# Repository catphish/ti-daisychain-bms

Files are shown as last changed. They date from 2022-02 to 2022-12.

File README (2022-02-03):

TI Daisychain BMS Master
========================

BMS master for daisychained bq76PL455A slave modules.

This board will communicate with up to 3 strings of bq76PL455A battery
modules. Each string supports up to 16 modules, and each module supports
up to 16 cells. A common configuration is 3 strings of 6 modules but any
combination is supported.

The board will read the voltages of all detected cells and will perform
balancing as well as reporting data over CAN.

Connector J1
=============

------------------------
| CANH | WAKE1 | WAKE2 |
| CANL |  GND  |  +12V |
------------------------

The low voltage connector J1 has 3 functions:

1) Connect +12v to a permanent positive suppy (5v - 14v)
2) Connect CANH and CANL to a CAN bus.
3) Connect WAKE1 and WAKE2 to switched voltage sources

If either WAKE1 OR WAKE2 is live (+5v to +14v) theh the board will wake
up and monitor the pack. If both are off (0v) then the board will finish
any in-progress balancing, then go into a low power sleep mode.

It is recommended to connect WAKE1 to ignition live, and WAKE2 to a 12V
output generated by a charger. This will ensure that the cells are monitored
during both charge and discharge.

Connector J2, J3, J4
====================

Each of the BATT1, BATT2 and BATT3 (J2,J3,J4) may be connected to the data
pins of a bq76PL455A battery module. All three are optional, and all three
support a full chain of up to 16 battery modules, or any partial chain.
Chain lengths do not have to be matched. The pinout of the battery module
is beyong the scope of this document.

Power Modes
===========

When either WAKE1 or WAKE2 are high, the module will enter active mode. In
this mode, it will continuously monitor the voltage of all attached cells.
Data including the pack voltage, high and low cell voltages, and temperatures
will be send to the CAN bus at 1 second intervals. Balancing will take place
if necessary. For further details of balancing see the next section.

When WAKE1 and WAKE2 are both low, and balancing is complete, the board will
enter a low power sleep mode. In this mode, the board consumes approximately
600uA (0.6mA) at 12V and will perform no actions until woken again. The
bq76PL455A modules will also anter a low power state, consuming close to zero
power from the high voltage pack.

Balancing
=========

If any cell voltage is detected as being higher than 4.0V and more than 10mV
higher than the lowest recorded cell voltage, it will be bled until one of
these ocnditions is no longer met. To prevent excessive heat, only one cell
in each battery (16 cell module) will be bled simultaneously. If multiple cells
meet the criteria, the cell with the highest voltage will be selected.
Balancing will be considered complete when no cells meet the criteria for
balancing.

CAN Messages Received
=====================

This modules does not receive CAN messages.

CAN Messages Sent
=================

--------------------------------------------------------------------------------
| CAN ID | Byte 0-3           | Byte 4-5          | Byte 6      | Byte 7       |
| 0x4f0  | Total Pack Voltage | Balance Threshold | Error count | Module count |
--------------------------------------------------------------------------------

Total pack voltage it the sum of all modules. For parallel packs this value
will be a multiple of the real pack voltage.

Balance threshold will be a non-zero value when balancing is active and
indicates the target voltage, generally this will be 10mV higher than the
minimum cell voltage.

--------------------------------------------------------------------
| CAN ID | Byte 0-1   | Byte 2-3   | Byte 4-5      | Byte 6-7      |
| 0x4f1  | Max Cell V | Min Cell V | Max Cell Temp | Min Cell Temp |
--------------------------------------------------------------------

All values are big endian. Voltage values should be interpreted by dividing
the value by 13107. Temperature values are 

The following calculation can be used to convert the readong for an External NTC to a temperature:

float temperature(uint16_t adc) {
  float r = 0.0000000347363427499292f * adc * adc - 0.001025770762903f * adc + 2.68235340614337f;
  float t = log(r) * -30.5280964239816f + 95.6841501312447f;
  return t;
}

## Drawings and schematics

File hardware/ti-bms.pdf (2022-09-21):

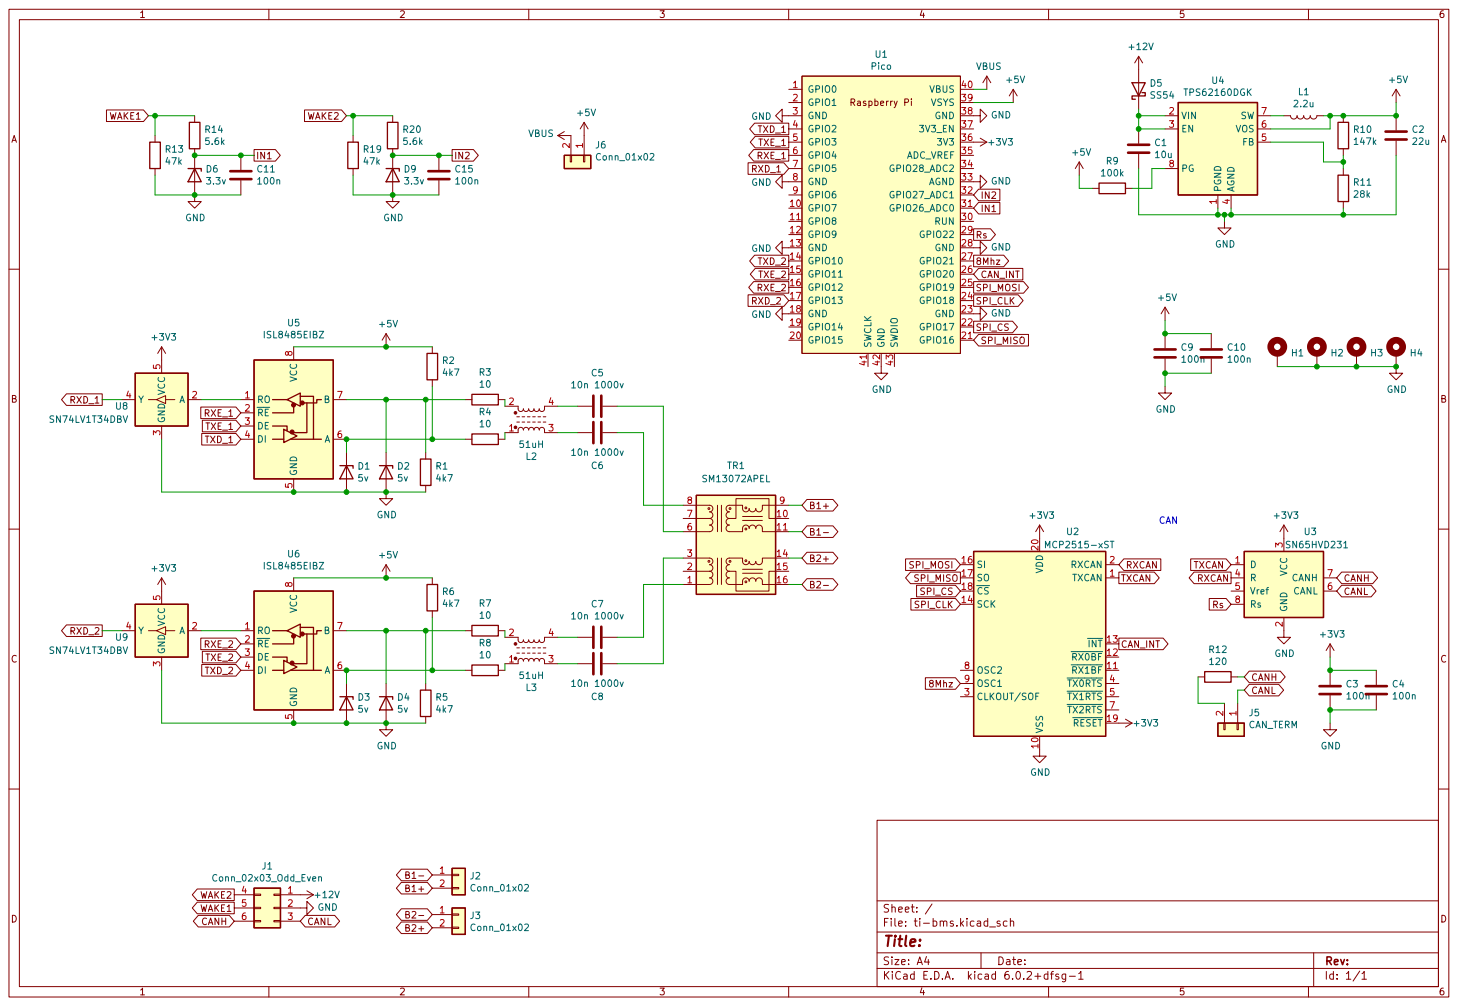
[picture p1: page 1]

4 FB 5 VOS 6 SW 7 PG 8 U4 TPS62160DGK GND
IN2 SPI_CS

File: ti-bms.kicad_sch Sheet: /
Id: 1/1 Title:

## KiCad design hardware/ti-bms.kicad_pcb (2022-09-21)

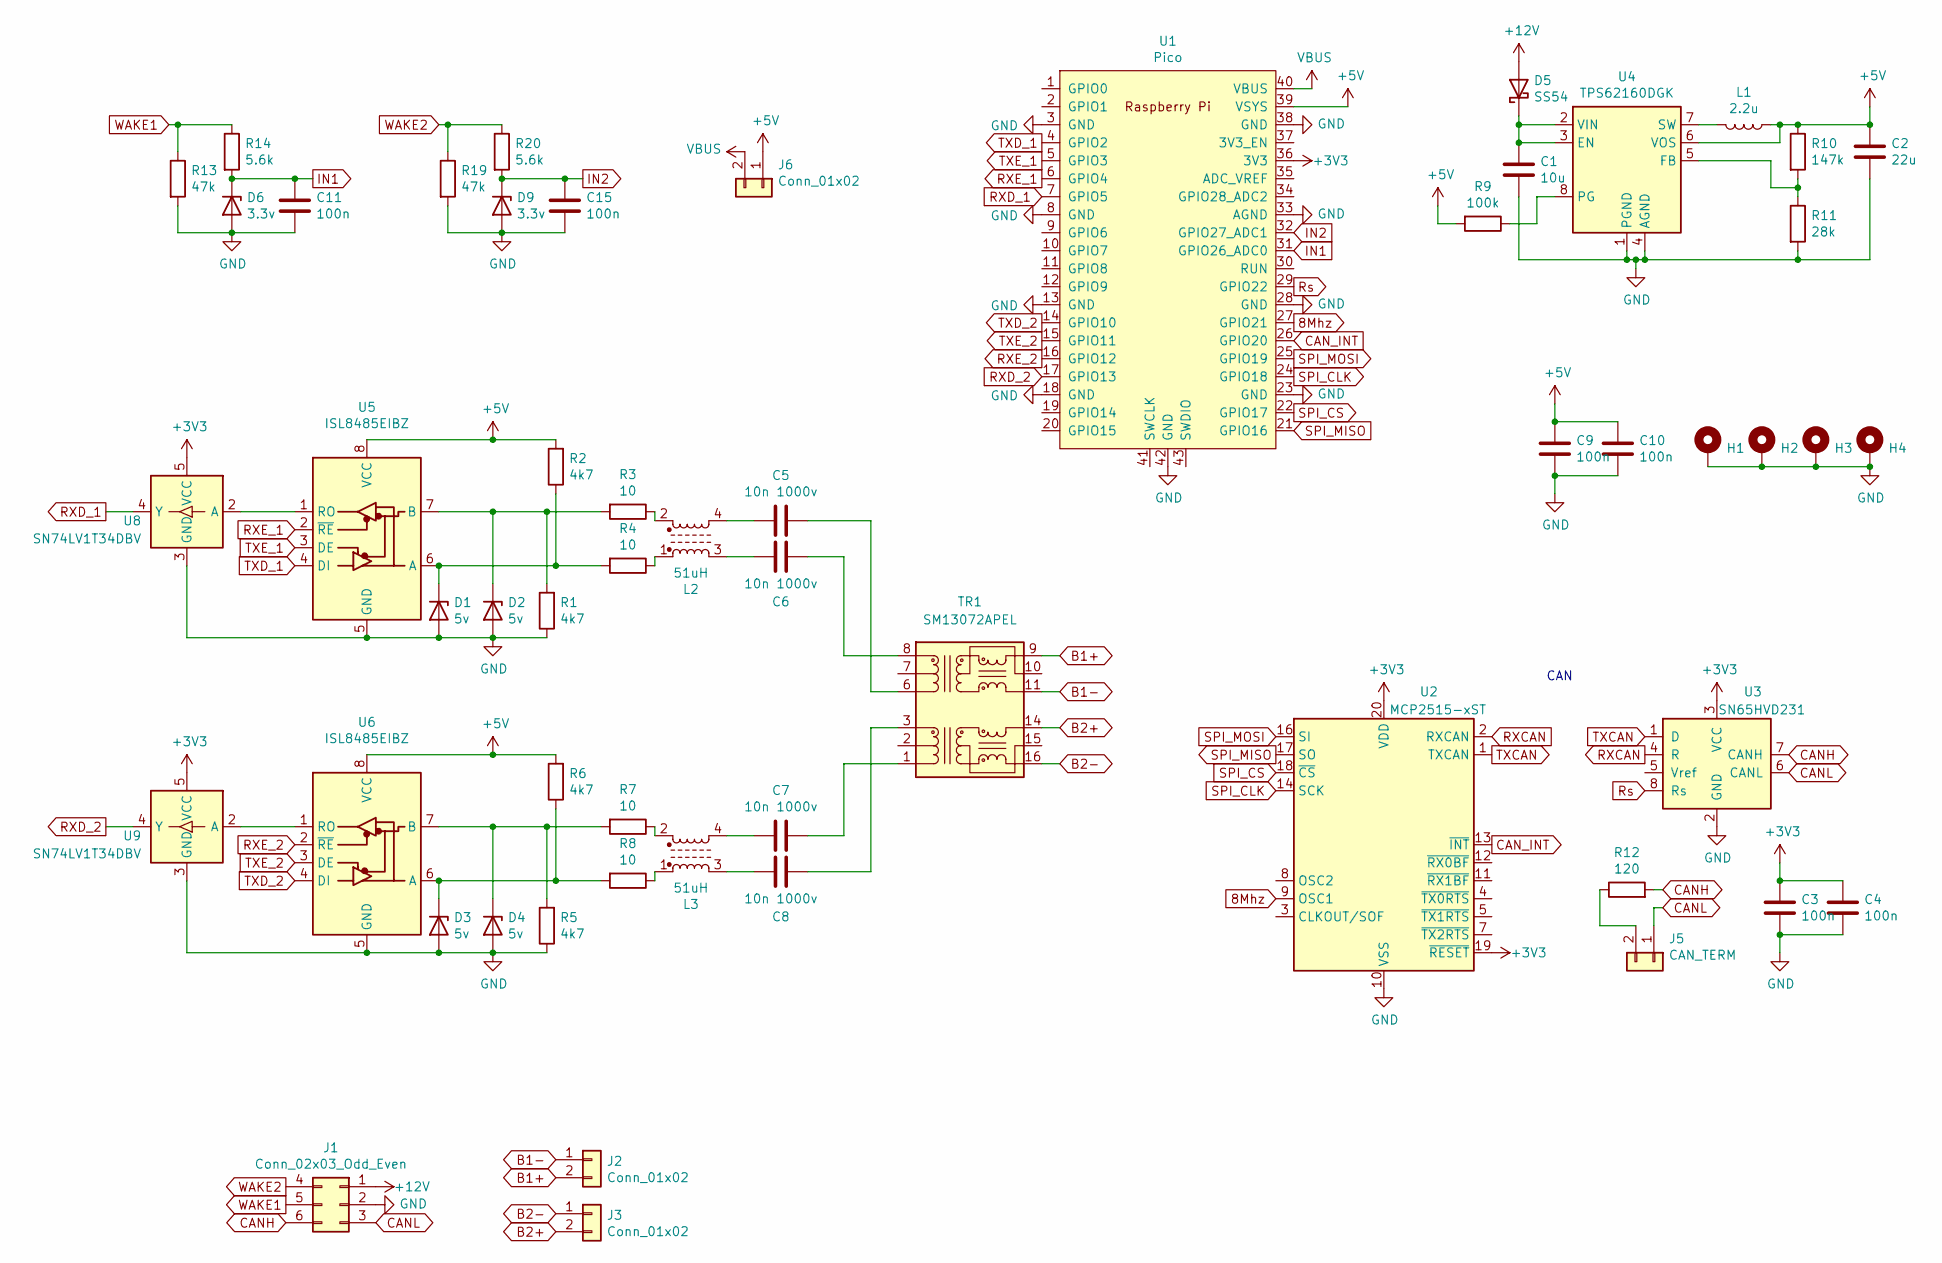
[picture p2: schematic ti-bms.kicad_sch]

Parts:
C1: 10u; C_1210_3225Metric; LCSC C77102
C2: 22u; C_1206_3216Metric; LCSC C5672
C3, C4, C9, C10, C11, C15: 100n; C_0603_1608Metric; LCSC C14663
C5, C6, C7, C8: 10n 1000v; C_1206_3216Metric; LCSC C9194
D1, D2, D3, D4: 5v; SOD882; LCSC C85401
D5: SS54; D_SMA; LCSC C22452
D6, D9: 3.3v; D_MiniMELF; LCSC C8056
H1, H2, H3, H4: MountingHole; MountingHole_3.2mm_M3_Pad
J1: Conn_02x03_Odd_Even; Molex_Micro-Fit_3.0_43045-0600_2x03_P3.00mm_Horizontal
J2, J3: Conn_01x02; Molex_Micro-Fit_3.0_43650-0200_1x02_P3.00mm_Horizontal
J5: CAN_TERM; PinHeader_1x02_P2.54mm_Vertical
J6: Conn_01x02; PinHeader_1x02_P2.54mm_Vertical
L1: 2.2u; L_Neosid_SMS-ME3015; LCSC C43389
L2, L3: 51uH; ACT45B-101-2P-TL003; LCSC C76584
R1, R2, R5, R6: 4k7; R_0603_1608Metric; LCSC C23162
R3, R4, R7, R8: 10; R_0603_1608Metric; LCSC C22859
R9: 100k; R_0603_1608Metric; LCSC C25803
R10: 147k; R_0603_1608Metric; LCSC C22878
R11: 28k; R_0603_1608Metric; LCSC C22989
R12: 120; R_1206_3216Metric; LCSC C17909
R13, R19: 47k; R_0603_1608Metric; LCSC C25819
R14, R20: 5.6k; R_0603_1608Metric; LCSC C23189
TR1: SM13072APEL; Transformer_Ethernet_Wuerth_749013011A; LCSC C129155
U1: Pico; RPi_Pico_SMD_TH
U2: MCP2515-xST; TSSOP-20_4.4x6.5mm_P0.65mm; LCSC C15193
U3: SN65HVD231; SOIC-8_3.9x4.9mm_P1.27mm; LCSC C129257
U4: TPS62160DGK; MSOP-8_3x3mm_P0.65mm; LCSC C60726
U5, U6: ISL8485EIBZ; SOP-8_3.9x4.9mm_P1.27mm; LCSC C382024
U8, U9: SN74LV1T34DBV; SOT-23-5; LCSC C100024

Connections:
8Mhz: U1.27 (GPIO21), U2.9 (OSC1)
+3V3: C3.1, C4.1, U1.36 (3V3), U2.19 (~RESET), U2.20 (VDD), U3.3 (VCC), U8.5 (VCC), U9.5 (VCC)
+5V: C2.1, C9.1, C10.1, J6.1, L1.1, R2.2, R6.2, R9.2, R10.1, U1.39 (VSYS), U4.6 (VOS), U5.8 (VCC), U6.8 (VCC)
+12V: D5.2 (A), J1.1
B1+: J2.2, TR1.9 (RX-)
B1-: J2.1, TR1.11 (RX+)
B2+: J3.2, TR1.14 (TX-)
B2-: J3.1, TR1.16 (TX+)
CANH: J1.6, R12.2, U3.7 (CANH)
CANL: J1.3, J5.1, U3.6 (CANL)
CAN_INT: U1.26 (GPIO20), U2.13 (~INT)
GND: C1.2, C2.2, C3.2, C4.2, C9.2, C10.2, C11.2, C15.2, D1.2 (A), D2.2 (A), D3.2 (A), D4.2 (A), D6.2 (A), D9.2 (A), H1.1, H2.1, H3.1, H4.1, J1.2, R1.1, R5.1, R11.2, R13.2, R19.2, U1.3 (GND), U1.8 (GND), U1.13 (GND), U1.18 (GND), U1.23 (GND), U1.28 (GND), U1.33 (AGND), U1.38 (GND), U1.42 (GND), U2.10 (VSS), U3.2 (GND), U4.1 (PGND), U4.4 (AGND), U5.5 (GND), U6.5 (GND), U8.3 (GND), U9.3 (GND)
IN1: C11.1, D6.1 (K), R14.2, U1.31 (GPIO26_ADC0)
IN2: C15.1, D9.1 (K), R20.2, U1.32 (GPIO27_ADC1)
unnamed: C1.1, D5.1 (K), U4.2 (VIN), U4.3 (EN)
unnamed: C5.1, TR1.6 (RD+)
unnamed: C5.2, L2.4
unnamed: C6.1, TR1.8 (RD-)
unnamed: C6.2, L2.3
unnamed: C7.1, TR1.1 (TD+)
unnamed: C7.2, L3.4
unnamed: C8.1, TR1.3 (TD-)
unnamed: C8.2, L3.3
unnamed: D1.1 (K), R2.1, R4.2, U5.6 (A)
unnamed: D2.1 (K), R1.2, R3.2, U5.7 (B)
unnamed: D3.1 (K), R6.1, R8.2, U6.6 (A)
unnamed: D4.1 (K), R5.2, R7.2, U6.7 (B)
unnamed: J5.2, R12.1
unnamed: L1.2, U4.7 (SW)
unnamed: L2.1, R4.1
unnamed: L2.2, R3.1
unnamed: L3.1, R8.1
unnamed: L3.2, R7.1
unnamed: R9.1, U4.8 (PG)
unnamed: R10.2, R11.1, U4.5 (FB)
unnamed: U5.1 (RO), U8.2 (A)
unnamed: U6.1 (RO), U9.2 (A)
RXCAN: U2.2 (RXCAN), U3.4 (R)
RXD_1: U1.7 (GPIO5), U8.4 (Y)
RXD_2: U1.17 (GPIO13), U9.4 (Y)
RXE_1: U1.6 (GPIO4), U5.2 (~RE)
RXE_2: U1.16 (GPIO12), U6.2 (~RE)
Rs: U1.29 (GPIO22), U3.8 (Rs)
SPI_CLK: U1.24 (GPIO18), U2.14 (SCK)
SPI_CS: U1.22 (GPIO17), U2.18 (~CS)
SPI_MISO: U1.21 (GPIO16), U2.17 (SO)
SPI_MOSI: U1.25 (GPIO19), U2.16 (SI)
TXCAN: U2.1 (TXCAN), U3.1 (D)
TXD_1: U1.4 (GPIO2), U5.4 (DI)
TXD_2: U1.14 (GPIO10), U6.4 (DI)
TXE_1: U1.5 (GPIO3), U5.3 (DE)
TXE_2: U1.15 (GPIO11), U6.3 (DE)
VBUS: J6.2, U1.40 (VBUS)
WAKE1: J1.5, R13.1, R14.1
WAKE2: J1.4, R19.1, R20.1

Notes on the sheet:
CAN

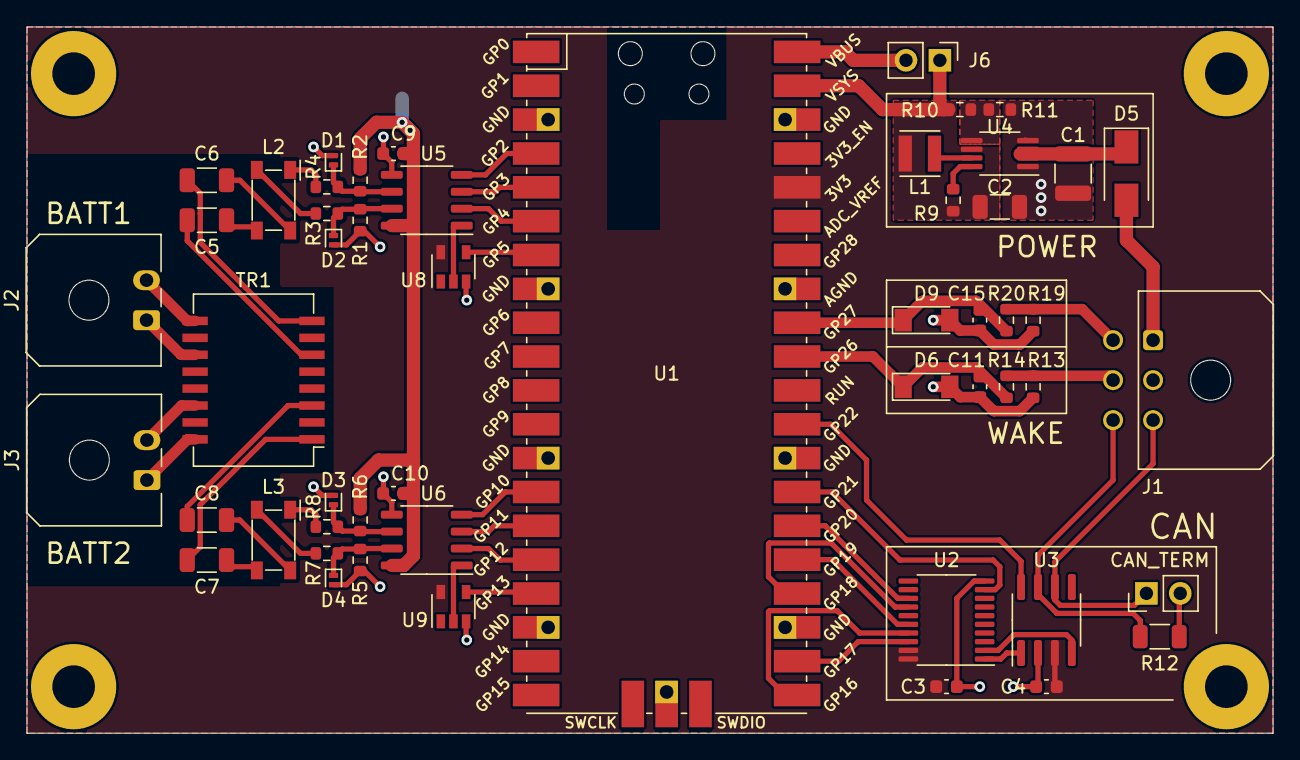
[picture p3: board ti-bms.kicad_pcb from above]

Board: 2 copper layers, 93.5 x 53.0 mm, 56 parts (0 on the bottom side), 55 nets.

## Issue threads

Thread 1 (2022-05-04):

Poor performance on long or noisy links

catphish, 2022-05-04:
After initial testing, the BMS does not successfully communicate with batteries on cable lengths exceeding 1m, nor if any electrical noise is present. The following changes will almost certainly improve matters and need to be tested:

* Increase inductance of common mode filter from 22uH to 100uH. Datasheet recommends minimum of 50uH.
* Increase capacitance of isolation capacitors from 1nF to 4.7nF or 10nF.

Additionally, the following *might* help.

* Increase resistance of pull-ups and pull-downs from 1k to 4.7k or 10k.

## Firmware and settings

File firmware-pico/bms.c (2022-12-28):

#include <math.h>
#include <stdio.h>

#include "bms.pio.h"
#include "can.h"
#include "device/usbd.h"
#include "hardware/clocks.h"
#include "hardware/pio.h"
#include "hardware/pll.h"
#include "hardware/regs/io_bank0.h"
#include "hardware/regs/usb.h"
#include "hardware/rosc.h"
#include "hardware/spi.h"
#include "hardware/structs/usb.h"
#include "hardware/sync.h"
#include "hardware/xosc.h"
#include "pico/sleep.h"
#include "pico/stdlib.h"

// Number of parallel strings
#define PARALLEL_STRINGS 1
// Number of modules
#define MODULES_1 10
#define MODULES_2 0

// Min absolute voltage to enable balancing.
// 52428 = 4.0V, 53738 = 4.1V, 54525 = 4.16V
#define BALANCE_MIN 52428
// Min difference to enable balancing. 131 = 10mV
#define BALANCE_DIFF 131
// Number of cells per module to bleed simultaneously
#define MAX_BALANCE_CELLS 1

// It should not be necessary for most users to change anything below this
// point.

// The number of battery interfaces on the board
#define CHAIN_COUNT 2
#define MAX_MODULES (16 * CHAIN_COUNT)

// Hardware wakeup pins
#define WAKE1 26
#define WAKE2 27

// Define pins for SPI (to CAN)
#define SPI_PORT spi0
#define SPI_MISO 16
#define SPI_CS 17
#define SPI_CLK 18
#define SPI_MOSI 19
#define CAN_INT 20    // Interrupt from CAN controller
#define CAN_CLK 21    // 8MHz clock for CAN
#define CAN_SLEEP 22  // Shut down CAN transceiver

// Struct for RS485 transceiver info
struct battery_interface {
  uint16_t serial_out;
  uint16_t serial_master;
  uint16_t serial_enable;
  uint16_t serial_in;
  uint16_t module_count;
  uint16_t sm;
};

// Define pins for RS485 transceivers
struct battery_interface battery_interfaces[3] = {{
                                                      .serial_out = 2,
                                                      .serial_master = 3,
                                                      .serial_enable = 4,
                                                      .serial_in = 5,
                                                      .module_count = MODULES_1,
                                                      .sm = 0,
                                                  },
                                                  {
                                                      .serial_out = 10,
                                                      .serial_master = 11,
                                                      .serial_enable = 12,
                                                      .serial_in = 13,
                                                      .module_count = MODULES_2,
                                                      .sm = 1,
                                                  }};

// Buffers for received data
uint8_t rx_data_buffer[128];

// Other global variables
uint8_t error_count = 0;
uint16_t balance_threshold = 0;
uint16_t cell_voltage[MAX_MODULES][16];
uint16_t aux_voltage[MAX_MODULES][8];
uint16_t balance_bitmap[MAX_MODULES];
uint32_t pack_voltage = 0;

// Variables for balancing process and reporting
uint16_t max_voltage;
uint16_t min_voltage;
uint16_t max_temperature;
uint16_t min_temperature;

// Timer
uint8_t rewake;  // Whether the modules need to be woken up on next execution

// PIO and state machine selection
#define SM_SQ 0

void SPI_configure() {
  spi_init(SPI_PORT, 1000000);
  spi_set_format(SPI_PORT, 8, 0, 0, SPI_MSB_FIRST);
  gpio_set_function(SPI_MISO, GPIO_FUNC_SPI);
  gpio_set_function(SPI_MOSI, GPIO_FUNC_SPI);
  gpio_set_function(SPI_CLK, GPIO_FUNC_SPI);
  gpio_init(SPI_CS);
  gpio_set_dir(SPI_CS, GPIO_OUT);
  gpio_put(SPI_CS, 1);
}

void CAN_reset() {
  gpio_put(SPI_CS, 0);
  spi_write_blocking(SPI_PORT, (uint8_t[]){CMD_RESET}, 1);
  gpio_put(SPI_CS, 1);
  busy_wait_us(100);
}

uint8_t CAN_reg_read(uint8_t reg) {
  uint8_t data;
  gpio_put(SPI_CS, 0);
  spi_write_blocking(SPI_PORT, (uint8_t[]){CMD_READ, reg}, 2);
  spi_read_blocking(SPI_PORT, 0, &data, 1);
  gpio_put(SPI_CS, 1);
  return (data);
}

void CAN_reg_write(uint8_t reg, uint8_t val) {
  gpio_put(SPI_CS, 0);
  spi_write_blocking(SPI_PORT, (uint8_t[]){CMD_WRITE, reg, val}, 3);
  gpio_put(SPI_CS, 1);
}

void CAN_reg_modify(uint8_t reg, uint8_t mask, uint8_t val) {
  gpio_put(SPI_CS, 0);
  busy_wait_us(2);
  spi_write_blocking(SPI_PORT, (uint8_t[]){CMD_MODIFY, reg, mask, val}, 4);
  busy_wait_us(2);
  gpio_put(SPI_CS, 1);
}

void CAN_configure(uint16_t id) {
  // Configure speed to 500kbps based on 8MHz Crystal
  // Magic constants from
  // https://github.com/sandeepmistry/arduino-CAN/blob/master/src/MCP2515.cpp
  CAN_reg_write(REG_CNF1, 0x00);
  CAN_reg_write(REG_CNF2, 0x90);
  CAN_reg_write(REG_CNF3, 0x02);

  // Enable Filters
  CAN_reg_write(REG_RXBnCTRL(0), 1 << 2);  // Enable rollover from BUF0 to BUF1
  CAN_reg_write(REG_RXBnCTRL(1), 0);
  // Set masks for RXB0 and RXB1 the same
  for (int n = 0; n < 2; n++) {
    uint16_t mask = 0x7ff;
    CAN_reg_write(REG_RXMnSIDH(n), mask >> 3);
    CAN_reg_write(REG_RXMnSIDL(n), mask << 5);
    CAN_reg_write(REG_RXMnEID8(n), 0);
    CAN_reg_write(REG_RXMnEID0(n), 0);
  }
  // Set match ID for all filters the same
  for (int n = 0; n < 6; n++) {
    CAN_reg_write(REG_RXFnSIDH(n), id >> 3);
    CAN_reg_write(REG_RXFnSIDL(n), id << 5);
    CAN_reg_write(REG_RXFnEID8(n), 0);
    CAN_reg_write(REG_RXFnEID0(n), 0);
  }

  // Enable receive interrupts
  CAN_reg_write(REG_CANINTE, 3);

  // Set normal operation mode
  CAN_reg_write(REG_CANCTRL, MODE_NORMAL);
}

void CAN_transmit(uint16_t id, uint8_t* data, uint8_t length) {
  CAN_reg_write(REG_TXBnSIDH(0), id >> 3);  // Set CAN ID
  CAN_reg_write(REG_TXBnSIDL(0), id << 5);  // Set CAN ID
  CAN_reg_write(REG_TXBnEID8(0), 0x00);     // Extended ID
  CAN_reg_write(REG_TXBnEID0(0), 0x00);     // Extended ID

  CAN_reg_write(REG_TXBnDLC(0), length);  // Frame length

  for (int i = 0; i < length; i++) {  // Write the frame data
    CAN_reg_write(REG_TXBnD0(0) + i, data[i]);
  }

  CAN_reg_write(REG_TXBnCTRL(0), 0x08);              // Start sending
  busy_wait_us(1000);                                // Allow up to 1ms to transmit
  CAN_reg_write(REG_TXBnCTRL(0), 0);                 // Stop sending
  CAN_reg_modify(REG_CANINTF, FLAG_TXnIF(0), 0x00);  // Clear interrupt flag
}

// Calculate message CRC.
uint16_t crc16(uint8_t* message, uint8_t length) {
  uint16_t crc = 0;
  uint16_t j;
  while (length--) {
    crc ^= *message++;
    for (j = 0; j < 8; j++) {
      crc = (crc >> 1) ^ ((crc & 1) ? 0xa001 : 0);
    }
  }
  return crc;
}

// Deactivate the TX PIO and send a square wave to wake up the device
void wakeup(struct battery_interface* battery_interface) {
  // Enable the line driver
  gpio_put(battery_interface->serial_enable, 0);
  // Disable TX PIO
  pio_sm_set_enabled(pio0, battery_interface->sm, false);
  // Wait for it to be disabled
  busy_wait_ms(1);
  // Loop for 100 x 10us
  for (int n = 0; n < 100; n++) {
    pio_sm_set_pins(pio0, battery_interface->sm, (1 << battery_interface->serial_master) | (1 << battery_interface->serial_out));  // Drive DO high (DE enabled)
    busy_wait_us(2);
    pio_sm_set_pins(pio0, battery_interface->sm, (1 << battery_interface->serial_master) | (0 << battery_interface->serial_out));  // Drive DO low (DE enabled)
    busy_wait_us(2);
  }
  pio_sm_set_pins(pio0, battery_interface->sm, (1 << battery_interface->serial_master) | (1 << battery_interface->serial_out));  // Drive DO high (DE enabled)
  busy_wait_us(2);
  // Disable DE, stop driving bus
  pio_sm_set_pins(pio0, battery_interface->sm, 0);
  // Re-enable TX PIO
  pio_sm_set_enabled(pio0, battery_interface->sm, true);
}

// Send a command string
void send_command(struct battery_interface* battery_interface, uint8_t* command, uint8_t length) {
  uint16_t crc = crc16(command, length);
  // Append framing but to the first byte and send it
  pio_sm_put_blocking(pio0, battery_interface->sm, command[0] | 0x100);
  // Send remaining bytes
  for (int n = 1; n < length; n++) pio_sm_put_blocking(pio0, battery_interface->sm, command[n]);
  // Send CRC16
  pio_sm_put_blocking(pio0, battery_interface->sm, crc & 0xFF);
  pio_sm_put_blocking(pio0, battery_interface->sm, crc >> 8);
  busy_wait_us(20);  // Always insert a short pause after sending commands
}

// Receive data from PIO into a local buffer, size limit and timeout in
// microseconds specified It's probably unnecessary to do this with an interrupt
// because we know when we expect to receive data
uint16_t receive_data(struct battery_interface* battery_interface, uint8_t* buffer, uint16_t size, uint32_t timeout) {
  uint16_t rx_data_offset = 0;
  // Return immediately if size is zero
  if (size == 0) return 0;
  // Loop until timeout expires
  for (int n = 0; n < timeout; n++) {
    // Check for data in input FIFO
    while (!pio_sm_is_rx_fifo_empty(pio1, battery_interface->sm)) {
      // Receive one byte
      buffer[rx_data_offset++] = pio_sm_get_blocking(pio1, battery_interface->sm);
      // Return full size if we've filled the string
      if (rx_data_offset == size) return size;
    }
    // Sleep 1 microsecond each loop
    busy_wait_us(1);
  }
  // Return partial length received
  return rx_data_offset;
}

// Configure all daisychained packs with sequential addresses
void configure(struct battery_interface* battery_interface) {
  // Fully Enable Differential Interfaces and Select Auto-Addressing Mode
  send_command(battery_interface, (uint8_t[]){0xF2, 0x10, 0x10, 0xE0}, 4);
  // Configure the bq76PL455A-Q1 device to use auto-addressing to select address
  send_command(battery_interface, (uint8_t[]){0xF1, 0x0E, 0x10}, 3);
  // Configure the bq76PL455A-Q1 device to enter auto-address mode
  send_command(battery_interface, (uint8_t[]){0xF1, 0x0C, 0x08}, 3);
  // Configure 16 devices with sequential addresses
  for (int n = 0; n < 16; n++) {
    send_command(battery_interface, (uint8_t[]){0xF1, 0x0A, n}, 3);
  }
}

// Request that all packs simultaneously sample voltage
void sample_all() {
  // 0xFF 0xFF 0xFF - these 24 bits enable sampling of 16 cell voltages and
  //                  8 AUX channels. Some will contain temperature data.
  //                  16x oversampling.
  for (int n = 0; n < CHAIN_COUNT; n++) send_command(battery_interfaces + n, (uint8_t[]){0xF6, 0x02, 0x00, 0xFF, 0xFF, 0xFF, 0x00, 0x04}, 8);
  // Wait for sampling to complete
  busy_wait_ms(10);
}

// Put all modules to sleep
void sleep_modules() {
  // Broadcast sleep command to each chain
  for (int n = 0; n < CHAIN_COUNT; n++) send_command(battery_interfaces + n, (uint8_t[]){0xF1, 0x0C, 0x48}, 3);
  // Wait a little for safety
  busy_wait_ms(1);
  // Disable line drivers
  for (int n = 0; n < CHAIN_COUNT; n++) gpio_put(battery_interfaces[n].serial_enable, 1);
  // Ensure modules are woken when needed again
  rewake = 1;
}

// Return 1 if all PCB temperature sensors on a module are above 1.0v
uint8_t pcb_below_temp(uint8_t module) {
  if (aux_voltage[module][3] < 13107) return 0;
  if (aux_voltage[module][4] < 13107) return 0;
  if (aux_voltage[module][5] < 13107) return 0;
  if (aux_voltage[module][6] < 13107) return 0;
  return 1;
}

// Dummy interrupt for hardware wakeup
void gpio_callback() {}

void reconfigure_clocks() {
  // Clock the peripherals, ref clk, and rtc from the 12MHz crystal oscillator
  clock_configure(clk_peri, 0, CLOCKS_CLK_PERI_CTRL_AUXSRC_VALUE_XOSC_CLKSRC, 12000000, 12000000);
  clock_configure(clk_ref, CLOCKS_CLK_REF_CTRL_SRC_VALUE_XOSC_CLKSRC, 0, 12000000, 12000000);
  clock_configure(clk_rtc, 0, CLOCKS_CLK_RTC_CTRL_AUXSRC_VALUE_XOSC_CLKSRC, 12000000, 46875);
  // Shut down unused clocks, PLLs and oscillators
  clock_stop(clk_adc);
  rosc_disable();
  // Disable more clocks when sleeping
  clocks_hw->sleep_en0 = CLOCKS_SLEEP_EN0_CLK_SYS_PLL_USB_BITS;
  clocks_hw->sleep_en1 = CLOCKS_SLEEP_EN1_CLK_SYS_TIMER_BITS | CLOCKS_SLEEP_EN1_CLK_SYS_XOSC_BITS | CLOCKS_SLEEP_EN1_CLK_USB_USBCTRL_BITS | CLOCKS_SLEEP_EN1_CLK_SYS_USBCTRL_BITS;
}

float voltage(uint16_t adc) {
  float v = adc;
  return (v / 13107.f);
}

float temperature(uint16_t adc) {
  float r = 0.0000000347363427499292f * adc * adc - 0.001025770762903f * adc + 2.68235340614337f;
  float t = log(r) * -30.5280964239816f + 95.6841501312447f;
  return t;
}

void deep_sleep() {
  // Deep sleep until woken by hardware;
  tud_disconnect();  // Disconnect USB
  CAN_reg_write(REG_CANCTRL, MODE_SLEEP);
  gpio_put(CAN_SLEEP, 1);  // Sleep the CAN transceiver
  uint32_t s = save_and_disable_interrupts();
  gpio_set_irq_enabled_with_callback(WAKE1, GPIO_IRQ_LEVEL_HIGH, true, &gpio_callback);
  gpio_set_irq_enabled_with_callback(WAKE2, GPIO_IRQ_LEVEL_HIGH, true, &gpio_callback);
  gpio_set_dormant_irq_enabled(WAKE1, GPIO_IRQ_LEVEL_HIGH, true);
  gpio_set_dormant_irq_enabled(WAKE2, GPIO_IRQ_LEVEL_HIGH, true);
  clocks_hw->sleep_en0 = 0;
  clocks_hw->sleep_en1 = 0;
  xosc_dormant();
  reconfigure_clocks();
  gpio_set_irq_enabled_with_callback(WAKE1, GPIO_IRQ_LEVEL_HIGH, false, &gpio_callback);
  gpio_set_irq_enabled_with_callback(WAKE2, GPIO_IRQ_LEVEL_HIGH, false, &gpio_callback);
  restore_interrupts(s);
  SPI_configure();
  gpio_put(CAN_SLEEP, 0);  // Wake the CAN transceiver
  CAN_reg_write(REG_CANCTRL, MODE_NORMAL);
  tud_connect();
  stdio_usb_init();  // Restore USB
}

int usb_suspended() { return (usb_hw->sie_status & USB_SIE_STATUS_SUSPENDED_BITS); }

int main() {
  // Set system clock to 80MHz, this seems like a reasonable value for the 4MHz
  // data
  set_sys_clock_khz(80000, true);
  stdio_init_all();
  reconfigure_clocks();
  // Used for program loading
  int offset;

  //  Used to keep track of battery voltage data stream
  uint8_t can_string = 0, can_module = 0, can_cell = 0;

  // Load and initialize the TX PIO program
  offset = pio_add_program(pio0, &daisychain_tx_program);
  for (int n = 0; n < CHAIN_COUNT; n++) daisychain_tx_program_init(pio0, battery_interfaces[n].sm, offset, battery_interfaces[n].serial_out, battery_interfaces[n].serial_master);

  // Load and initialize the RX PIO program
  offset = pio_add_program(pio1, &daisychain_rx_program);
  for (int n = 0; n < CHAIN_COUNT; n++) daisychain_rx_program_init(pio1, battery_interfaces[n].sm, offset, battery_interfaces[n].serial_in, battery_interfaces[n].serial_master);

  // Configure serial enable pins
  for (int chain = 0; chain < CHAIN_COUNT; chain++) {
    gpio_init(battery_interfaces[chain].serial_enable);
    gpio_set_dir(battery_interfaces[chain].serial_enable, GPIO_OUT);
  }

  // Configure hardware wakeup pins
  gpio_init(WAKE1);
  gpio_init(WAKE2);
  gpio_set_dir(WAKE1, GPIO_IN);
  gpio_set_dir(WAKE2, GPIO_IN);
  gpio_disable_pulls(WAKE1);
  gpio_disable_pulls(WAKE2);

  // Configure CAN transceiver sleep line
  gpio_init(CAN_SLEEP);
  gpio_set_dir(CAN_SLEEP, GPIO_OUT);
  gpio_put(CAN_SLEEP, 0);  // Logic low to wake transceiver

  // Output 8MHz square wave on CAN_CLK pin
  clock_gpio_init(CAN_CLK, CLOCKS_CLK_GPOUT0_CTRL_AUXSRC_VALUE_CLKSRC_PLL_SYS, 10);

  // Configure SPI to communicate with CAN
  SPI_configure();
  // Set up CAN to receive messages
  CAN_reset();
  CAN_configure(0x4F8);

  // Wake modules immediately
  rewake = 1;
  // Main loop.
  while (1) {
    // Start counter for total voltage
    pack_voltage = 0;

    // If we've been sleeping, wake the modules
    if (rewake) {
      rewake = 0;
      // Wake and reset up the modules
      for (int n = 0; n < CHAIN_COUNT; n++) wakeup(battery_interfaces + n);

      // Give the modules time to reset
      busy_wait_ms(10);

      // Configure the module addresses
      for (int n = 0; n < CHAIN_COUNT; n++) configure(battery_interfaces + n);
    }

    for (int chain = 0; chain < CHAIN_COUNT; chain++) {
      // Set discharge timeout (1min, all modules)
      send_command(battery_interfaces + chain, (uint8_t[]){0xF1, 0x13, (2 << 4) | (1 << 3)}, 3);
      // Disable discharge (all modules)
      send_command(battery_interfaces + chain, (uint8_t[]){0xF2, 0x14, 0, 0}, 4);
      // Set communication timeout (10s) (all modules)
      send_command(battery_interfaces + chain, (uint8_t[]){0xF1, 0x28, (6 << 4)}, 3);
    }
    // Send a broadcast message to all modules in chain to simultaneously sample
    // all cells
    sample_all();

    // Collect voltages and temperature data for all modules
    // We want to complete this loop as fast as possible because balancing must
    // be disabled during measurement
    max_voltage = 0;
    min_voltage = 65535;
    max_temperature = 65535;
    min_temperature = 0;
    for (int module = 0; module < MAX_MODULES; module++) {
      uint8_t chain = module / 16;
      uint8_t submodule = module % 16;
      if (submodule >= battery_interfaces[chain].module_count) continue;

      // Clear the input FIFO just in case
      pio_sm_clear_fifos(pio1, battery_interfaces[chain].sm);
      // Request sampled voltage data from module
      send_command(battery_interfaces + chain, (uint8_t[]){0x81, submodule, 0x02, 0x20}, 4);
      // Receive response data from PIO FIFO into CPU buffer - 51 bytes of data
      // with 10ms timeout 24 values * 2 bytes + length + 2 byte checksum = 51
      uint16_t received = receive_data(battery_interfaces + chain, rx_data_buffer, 51, 10000);
      // Check RX CRC
      uint16_t rx_crc = crc16(rx_data_buffer, 51);
      if (received == 51 && rx_crc == 0) {
        for (int cell = 0; cell < 16; cell++) {
          // nb. Cells are in reverse, cell 16 is reported first
          cell_voltage[module][cell] = rx_data_buffer[(15 - cell) * 2 + 1] << 8 | rx_data_buffer[(15 - cell) * 2 + 2];
          pack_voltage += cell_voltage[module][cell];
          if (cell_voltage[module][cell] > max_voltage) max_voltage = cell_voltage[module][cell];
          if (cell_voltage[module][cell] < min_voltage) min_voltage = cell_voltage[module][cell];
        }
        for (int aux = 0; aux < 8; aux++) {
          aux_voltage[module][aux] = rx_data_buffer[(16 + aux) * 2 + 1] << 8 | rx_data_buffer[(16 + aux) * 2 + 2];
        }
        for (int aux = 1; aux < 3; aux++) {
          // Higher temperatures mean lower values!
          if (aux_voltage[module][aux] < max_temperature) max_temperature = aux_voltage[module][aux];
          if (aux_voltage[module][aux] > min_temperature) min_temperature = aux_voltage[module][aux];
        }
      } else {
        if (received == 51)
          printf("CRC Error %i %i: %04x\n", chain, submodule, rx_crc);
        else
          printf("RX Error %i %i: %i\n", chain, submodule, received);
        error_count++;
        rewake = 1;
        balance_threshold = 0;
        goto softreset;
      }
    }

    // Work out if balancing is required
    if (max_voltage > BALANCE_MIN) {
      if (max_voltage > min_voltage + BALANCE_DIFF) {  // Min cell + 10mV
        // At least one cell is overcharged, lets balance!
        balance_threshold = min_voltage + BALANCE_DIFF;                        // Min cell + 10mV
        if (balance_threshold < BALANCE_MIN) balance_threshold = BALANCE_MIN;  // No less than BALANCE_MIN
      } else {
        // Cells are balanced
        balance_threshold = 0;
      }
    } else {
      // Under balancing threshold
      balance_threshold = 0;
    }

    // Balancing
    for (int module = 0; module < MAX_MODULES; module++) {
      uint8_t chain = module / 16;
      uint8_t submodule = module % 16;
      if (submodule >= battery_interfaces[chain].module_count) continue;
      balance_bitmap[module] = 0;
      // Only balance if conditions are appropriate
      if (pcb_below_temp(module) && balance_threshold)
        // Add up to MAX_BALANCE_CELLS to balancing bitmap
        for (int n = 0; n < MAX_BALANCE_CELLS; n++) {
          uint16_t max_v = 0;
          int8_t selected_cell = 0;
          // Loop over each cell
          for (int cell = 0; cell < 16; cell++) {
            // Ignore cell if already balancing
            if (balance_bitmap[module] & (1 << cell)) continue;
            // If cell is highest cell so far, provisionally select it
            if (cell_voltage[module][cell] > balance_threshold)
              if (cell_voltage[module][cell] > max_v) {
                selected_cell = cell + 1;
                max_v = cell_voltage[module][cell];
              }
          }
          // Add selected candidate to final bitmap
          if (selected_cell) balance_bitmap[module] |= (1 << (selected_cell - 1));
        }
      send_command(battery_interfaces + chain, (uint8_t[]){0x92, submodule, 0x14, balance_bitmap[module] >> 8, balance_bitmap[module]}, 5);
      if (!usb_suspended()) {
        for (int cell = 0; cell < 16; cell++) {
          float v = cell_voltage[module][cell] / 13107.f;
          printf("Module %i Cell %i Voltage: %.4f\n", module, cell, v);
        }
        printf("Module %i T1: %.2f T2: %.2f\n", module, temperature(aux_voltage[module][1]), temperature(aux_voltage[module][2]));
        printf("Module %i PCB: %.2f %.2f %.2f %.2f\n", module, voltage(aux_voltage[module][3]), voltage(aux_voltage[module][4]), voltage(aux_voltage[module][5]), voltage(aux_voltage[module][6]));
        printf("Module %i Balance: %02x\n", module, balance_bitmap[module]);
      }
    }
    if (!usb_suspended()) {
      float v = balance_threshold / 13107.f;
      printf("Balance Threshold: %.2f\n", v);
    }
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

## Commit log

2021-12-23 initial comit
    [ti-bms.kicad_pcb, ti-bms.sch]
2021-12-24 remove fill from isolated area
    [ti-bms.kicad_pcb]
2021-12-24 add missing 3d models
    [ti-bms.kicad_pcb]
2021-12-24 more on isolation
    [ti-bms.kicad_pcb]
2022-01-04 correct voltage conversion value
2022-01-08 add 12v input and output, connect CAN line driver sleep pin
    [ti-bms.kicad_pcb, ti-bms.sch]
2022-01-10 dual wake inputs
    [ti-bms.kicad_pcb, ti-bms.sch]
2022-01-10 update schematic and picture
2022-01-12 rework inputs
    [ti-bms.kicad_pcb, ti-bms.sch]
2022-01-13 finish inputs
    [ti-bms.kicad_pcb, ti-bms.sch]
2022-01-25 swap in available part
    [ti-bms.sch]
2022-05-13 add usb mode, remove superfluous code, fix receive timing, detect false start bits, hardcode module count
    [bms.c]
2022-05-15 v4 hardware with 5v line drivers
    [ti-bms.kicad_pcb, ti-bms.sch]
2022-05-21 refactor low power sleep
2022-05-22 print temperatures in USB mode
2022-05-24 add missing trace
    [ti-bms.kicad_pcb]
2022-05-24 change resistor value, better error logging, remove redundant code
    [ti-bms.sch]
2022-06-01 remove static USB mode, replace with dynamic USB detection
    [bms.c]
2022-07-14 transmit slow loop of individual cell voltages
2022-09-21 integrate transformer for more common mode rejection
    [ti-bms.kicad_pcb, ti-bms.kicad_sch]
